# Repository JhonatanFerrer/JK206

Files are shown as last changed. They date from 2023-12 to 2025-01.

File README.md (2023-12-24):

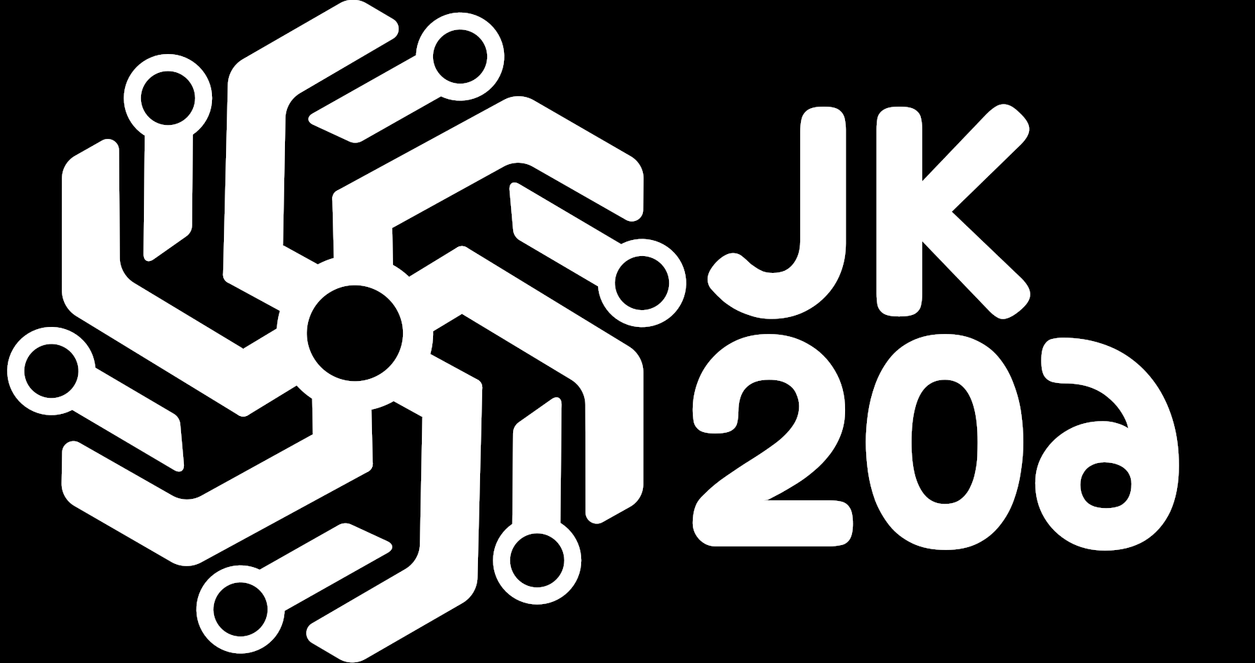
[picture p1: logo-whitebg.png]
Logo of the project


<h2 align="Left"> English </h2>

This project consists of a mechanical ortolinear keyboard design that is capable of being used for both a macropad and a 50% keyboard.

This is achieved through a modular design PCB that can be used by itself to mount a macropad with up to 20 keys (5 of them can be exchanged for encoders); while with three PCBs you can mount a keyboard with up to 60 keys (3 of them can be encoders)

The source code of the keyboard was written in CircuitPython using the <a href="http://kmkfw.io/">KMK firmware</a>, the microcontroller used is the Raspberry Pi Pico.

If you want to build your own JK206, go to the guide, where there will be the step-by-step to assemble and configure it

<strong>Note:</strong> If you just want to assemble your own JK206 and don't plan to modify anything of the PCB design, you don't need to touch the KiCAD files, directly use the Gerbers as the guide says

<h2 align="Left"> Español </h2>

Este proyecto consiste en un diseño de teclado mecánico ortolineal que es capaz de utilizarse tanto para un macropad como para un teclado 50%. 

Esto se consigue mediante una PCB de diseño modular que se puede usar por si misma para montar un macropad de hasta 20 teclas (5 de ellas se pueden cambiar por encoders); mientras que con tres PCBs se puede montar un teclado de hasta 60 teclas (3 de ellas pueden ser encoders)

El código fuente del teclado fue escrito en CircuitPython haciendo uso del <a href="http://kmkfw.io/">firmware KMK</a>, el microcontrolador utilizado es el Raspberry Pi Pico.

Si quieres armar tu propio JK206, entra en la guía, donde estará el paso a paso para ensamblarlo y configurarlo 

<strong>Nota:</strong> Si solo quieres montar tu propio JK206 y no piensan modificar nada del diseño de la PCB , no necesitas tocar los archivos de KiCAD, usa directamente los Gerbers como dice la guía

<h1 align="Left"> Photos / Fotos </h1>













These photos are from a prototype version of the project, the final version features some minor changes / Estas fotos son de una versión prototipo del proyecto, la versión final presenta algunos cambios menores

<h1 align="Left"> ToDo </h1>

1. Finish the Spanish guide and make the English guide. / Terminar la guía en español y hacer la guía en inglés
   
2. Make the keyboard compatible with <a href="https://peg.software/">Peg</a> / Hacer el teclado compatible con <a href="https://peg.software/">Peg</a>

3. Add the possibility to insert UNICODE characters (this causes keyboard crashes) / Agregar la posibilidad de insertar caracteres UNICODE (esto causa crasheos en el teclado)
  
4. Ensure that when the keyboard is connected, the computer does not display its storage, or at least displays it under the name JK206 / Hacer que al ser conectado el teclado, el computador no muestre su almacenamiento, o al menos lo muestre bajo el nombre Jk206

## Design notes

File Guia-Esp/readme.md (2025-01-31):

<h1 align="Left"> Guía ensamble </h1>

<h2 align="Left"> 1. Materiales Base</h2>

Para poder armar tu propio JK206, sea en su versión de macropad o de teclado 50%, necesitas los siguientes materiales:

| | Macropad | Teclado |
| --- | --- | --- |
| Switches mx | 15 - 20 (dependiendo el número de encoders) | 57 - 60 (dependiendo el número de encoders) |
| Sockets hotswap kailh | 15 - 20 (dependiendo el número de encoders) | 57 - 60 (dependiendo el número de encoders) |
| Encoders EC11 | 0 - 5 | 0 - 3 |
| Diodos 1n4148 | 20 | 60 |
| PCB JK206 | 1 | 3 |
| Raspberry Pi Pico | 1 | 1 |
| Pantalla OLED SSD1306 (0.91 o 0.96 pulgadas)  | 1 (opcional pero recomendada) | 1 (opcional pero recomendada) |
| Case | A preferencia | A preferencia |
| Keycaps | A preferencia | A preferencia |

Mas a continuación hablaremos de los tipos de case y que materiales en particular necesitan estos

Además de lo anterior, para poder realizar el montaje necesitarás de cautín/soldador y estaño, el flux de soldadura es opcional pero nunca viene mal para soldar

<h2 align="Left"> 2. Obtener la PCB </h2>

Para obtener las PCBs basta con tomar el gerber de la PCB (es un .zip) y mandarlo a hacer un una pagina de fabricación de PCBs. Solo hay que tener en cuenta que el número minimo de PCBs que se pueden mandar a hacer generalmente es de 5

<h2 align="Left"> 3. Preparar la PCB </h2>

Una vez tengas todos los materiales necesarios, toca empezar a soldar. Antes de empezar a soldar las piezas ten en cuenta lo siguiente según quieras montar un macropad o un teclado.

<h3 align="Left"> Para el macropad </h3>

Si estas montando el macropad, tienes que "habilitar" la opción de usar mas encoders en la PCB, para esto basta con unir los puntos de la PCB que se ven en la imagen, de forma que cada uno quede unido con quien tenga a sud derecha o izquierda

292385655-57addb74-b026-4cfa-8451-b28f55c42d1b

De forma que queden unidos de la siguiente manere



Esto se puede hacer tanto con cable UTP como con un jumper o uniendo directamente ambos puntos con estaño, basta con que haya continuidad entre ambos puntos

<h3 align="Left"> Para el teclado </h3>

Si estas montando el teclado, tienes que unir las 3 PCBs, para esto hay que unir filas y columnas; las columnas se unen en la parte superior de las PCBs de la siguiente forma:



Las filas se unen puenteando los puntos que se encuentran a los lados de la PCB junto al punto que le quede inmediatamente al lado de la otra PCB. Esto se hace en ambas intersecciones entre PCBs



No olvides que para evitar problemas posteriores con el montaje del teclado las 3 PCBs deben quedar completamente juntas y alineadas

<h2 align="Left"> 4. Soldar piezas </h2>

Ya con los preparativos listos, queda soldar los componentes en sus sitios correspondientes. Comienza colocando los diodos, estos van posicionados de forma que la parte que tiene una linea va hacia abajo, como se puede observar en la misma PCB



Lo siguiente sería soldar los sockets hotswap y los encoders, ten en cuenta que donde vayas a colocar enconders no hay que colocar sockets. Dependiendo de si estás armando un teclado o un macropad debes tener en cuenta las siguientes consideraciones:

<h3 align="Left"> Para el macropad </h3>

Los encoders se pueden colocar en el macropad de la siguiente forma



Las zonas verdes en el diagrama representan los puntos donde puenden colocarse los encoders. No es recomendable colocar dos encoders en posiciones que compartan el mismo número, pues por limitaciones del Raspberry Pi Pico y del diseño de la PCB estos serían reconocidos como un solo encoder; por lo que la formas recomendables de colocar los encoders serían las siguientes




<h3 align="Left"> Para el teclado </h3>

A pesar de tecnicamente poder poner encoders en la pcb de la izquierda en las posiciones 1, 2 y 3 mostradas en la sección anterior. Por cuestiones de usabilidad del teclado se recomienda solo poner un encoder en el extremo superior izquierdo.

Teniendo en cuenta lo anterior, empieza a soldar los sockets hotswap y los encoders que vayas a colocar. Puede que tengas problemas con los sockets, pero si eres generoso con el estaño no habrán mayores dificultades





Ahora solo faltaría soldar el Raspberry Pi Pico y la pantalla OLED. Es necesario que la Raspberry tenga pines soldados para poderla poner en la PCB, así que en caso de que tu Raspberry no los tenga de antemano tendrás que soldarle tu mismo unas regletas Antes de colocarla en la PCB.





En cuanto a la pantalla OLED, su posicionamiento varía dependiendo de cual pantalla vayas a usar. En caso de tener una pantalla rectangular de 0.91 pulgadas esta quedaría sobre la Raspberry, mientras que una pantalla cuadrada de 0.96 pulgadas quedaría a la derecha.




Nota: para el montaje del teclado, tanto la Raspberry como la pantalla van únicamente en la PCB de la izquierda. El diseño de la PCB no está pensado para que tomen ninguna otra posición.

<h2 align="Left"> 5. Montaje </h2>

Aquí el proceso cambia según el tipo de montaje que se quiera realizar:

<h3 align="Left"> Para el montaje sandwich-case </h3>

Para este montaje relativamente sencillo vas a necesitar de estos materiales:

| | Macropad | Teclado |
| --- | --- | --- |
| Separadores de latón M2 10mm | 4 | 4 |
| Tornillos M2 cabeza plana 6mm | 8 | 8 |
| Plates acrílicos (1.5mm de grosor)| [1 par](https://github.com/JhonatanFerrer/JK206/blob/main/Cases/Sandwich-Case/Macropad/Plates%20macropad.pdf)) | [1 par](https://github.com/JhonatanFerrer/JK206/blob/main/Cases/Sandwich-Case/Keyboard/Plates%20keyboard.pdf) |

Esta guía de montaje estará enfocada principalmente para el macropad, pero el montaje del JK206 en modo teclado es muy similar y la guía debería servir igualmente.

Para realizar el montaje del teclado o macropado lo primero será tomar el plate inferior y colocarle pies antideslizantes bajo preferencia del usuario.



Una vez hecho esto seguiría atornillar a éste los separadores





Nota: Los plates superior e inferior de la versión de teclado completo del JK206 tienen huecos para 12 separadores, aunque yo recomiendo usar solo 4 (2 al extremo derecho y 2 al extremo izquierdo),pero queda la opción de colocar mas separadores si se desea una sensación mas rígida al escribir

Ya teniendo nuestro plate inferior ahora vamos a sujetar nuestra PCB al plate superior con los switches, para esto basta con colocar un par de switches en el plate para luego colocarlos juntos en la PCB





Despues de esto quedaría colocar los switches faltantes



Ya teniendo unidos plate, pcb y switches podemos atornillar el plate superior a los separadores que habíamos colocado anteriormente en el plate inferior



Y con esto ya tenemos nuestro teclado o macropad listo, solo faltaría colocar keycaps a nuestro gusto y disfrutar.



<h4 align="Left"> Mods recomendados: </h4>
En general el tape mod funciona bien con el montaje, fuera de eso no hay mucho mas que se pueda hacer.

<h2 align="Left"> 5. Instalación del firmware </h2>

Ésta es la parte más fácil, para esto solo debes instalar [KMK](https://github.com/KMKfw/kmk_firmware/blob/main/docs/en/Getting_Started.md) en tu teclado o macropad siguiendo la guía de inicio rápido y sobre éste colocar los archivos de configuración, sean los del [macropad](https://github.com/JhonatanFerrer/JK206/tree/main/Source_Code/Macropad) o el [teclado completo](https://github.com/JhonatanFerrer/JK206/tree/main/Source_Code/Keyboard).

Y con ésto ya deberías tener completamente funcional tu JK206 :D

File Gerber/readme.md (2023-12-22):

<h2 align="Left"> English </h2>

Here are the Gerber files of the PCB, to send it to manufacture just upload the .zip file to your trusted PCB fabrication site (I recommend JLCPCB). When uploading the file to these pages you will get multiple options, just make sure that the PCB is manufactured in FR-4, that it has 2 layers and that it has a color of your liking; everything else you can leave untouched.

<h2 align="Left"> Español </h2>

Aquí se encuentran los archivos Gerber de la PCB, para mandarla a fabricar solo hace falta cargar el archivo .zip en tu página de fabricación de PCBs de confianza (yo recomiendo JLCPCB). Al subir el archivo a estas páginas van a salir multiples opciones, solo asegurate de que la PCB se fabrique en FR-4, que tenga 2 capas y que tenga un color de tu agrado; todo lo demás lo puedes dejar sin tocar.

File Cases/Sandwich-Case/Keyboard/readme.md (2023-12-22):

<h2 align="Left"> English </h2>

These are the PDF designs of the acrylic pieces needed for the Sandwich-Case type assembly of the keyboard. These pieces are designed to measure 2mm thick and can be made at any acrylic cutter shop by simply taking the PDF.

Remember that in order to assemble the macropad with this type of mounting you will also need a minimun of 8 M2 screws of 4 or 5mm along with 4 M2 spacers of 7mm, plus 6 rubber or silicone feet of your choice.

<h2 align="Left"> Español </h2>

Estos son los diseños en PDF de las piezas acrílicas necesarias para el montaje tipo Sandwich-Case del teclado. Estas piezas están pensadas para medir 2mm de grosor y se pueden mandar a hacer en cualquier local de venta y corte de acrilicos simplemente llevando el PDF

Recuerda que para poder armar el macropad con este tipo de montaje tambien vas a necesitar minimo 8 tornillos M2 de 4 o 5mm junto con 4 espaciadores M2 de 7mm, además de 6 pies de caucho o silicona de tu preferencia

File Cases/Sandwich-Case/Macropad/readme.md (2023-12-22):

<h2 align="Left"> English </h2>

These are the PDF designs of the acrylic pieces needed for the Sandwich-Case type assembly of the macropad. These pieces are designed to measure 2mm thick and can be made at any acrylic cutter shop by simply taking the PDF.

Remember that in order to assemble the macropad with this type of mounting you will also need 8 M2 screws of 4 or 5mm along with 4 M2 spacers of 7mm, plus 4 rubber or silicone feet of your choice.

<h2 align="Left"> Español </h2>

Estos son los diseños en PDF de las piezas acrílicas necesarias para el montaje tipo Sandwich-Case del macropad. Estas piezas están pensadas para medir 2mm de grosor y se pueden mandar a hacer en cualquier local de venta y corte de acrilicos simplemente llevando el PDF

Recuerda que para poder armar el macropad con este tipo de montaje tambien vas a necesitar 8 tornillos M2 de 4 o 5mm junto con 4 espaciadores M2 de 7mm, además de 4 pies de caucho o silicona de tu preferencia

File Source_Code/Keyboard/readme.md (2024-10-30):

<h2 align="Left"> English </h2>

This is the keyboard source code, to use it on your keyboard just put the files inside your keyboard following the tutorial. Don't forget that apart from needing to have CircuitPython with KMK, the keyboard needs the <a href="https://github.com/adafruit/Adafruit_CircuitPython_DisplayIO_SSD1306">DisplayIO_SSD1306</a> and <a href="https://github.com/adafruit/Adafruit_CircuitPython_Display_Text">CircuitPython_Display_Text</a> libraries.

This code assumes that the keyboard has a 0.96-inch SSD1306 OLED display, and the images were created with this in mind. In the guide there is a section for configuring the display

By default the way some symbols are written is set to Linux, but you can change it in the second line of main.py, changing SymbolsLinux to SymbolsWindows.



A Mac mode is not yet implemented

<h2 align="Left"> Español </h2>

Este es el código fuente del teclado, para usarlo en tu teclado solo pon los archivos dentro de tu teclado siguiendo el tutorial. No olvides que aparte de necesitar tener CircuitPython con KMK, el teclado necesita de las librerías <a href="https://github.com/adafruit/Adafruit_CircuitPython_DisplayIO_SSD1306">DisplayIO_SSD1306</a> y <a href="https://github.com/adafruit/Adafruit_CircuitPython_Display_Text">CircuitPython_Display_Text</a>

Este código asume que el teclado tiene una pantalla OLED SSD1306 de 0,96 pulgadas, además de que las imagenes fueron creadas tomando esto en cuenta. En la guía hay un apartado para configurar la pantalla.

De forma predeterminada la forma en que se escriben algunos símbolos está configurada para Linux, pero puede cambiarse en la segunda línea de main.py, cambiando SymbolsLinux a SymbolsWindows.



Aún no está implementado un modo para Mac

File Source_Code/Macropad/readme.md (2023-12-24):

<h2 align="Left"> English </h2>

This is the macropad source code, to use it on your keyboard just put the .py files inside your keyboard following the tutorial. Don't forget that apart from needing to have CircuitPython with KMK, the macropad needs the <a href="https://github.com/adafruit/Adafruit_CircuitPython_DisplayIO_SSD1306">DisplayIO_SSD1306</a> and <a href="https://github.com/adafruit/Adafruit_CircuitPython_Display_Text">CircuitPython_Display_Text</a> libraries.

This code assumes that the keyboard has a 0.91-inch SSD1306 OLED display, and the images were created with this in mind. In the guide there is a section for configuring the display.

By default the way some symbols are written is set to Linux, but you can change it in the second line of main.py, changing SymbolsLinux to SymbolsWindows.



A Mac mode is not yet implemented

<h2 align="Left"> Español </h2>

Este es el código fuente del macropad, para usarlo en tu teclado solo pon los archivos .py dentro de tu teclado siguiendo el tutorial. No olvides que aparte de necesitar tener CircuitPython con KMK, el macropad necesita de las librerías <a href="https://github.com/adafruit/Adafruit_CircuitPython_DisplayIO_SSD1306">DisplayIO_SSD1306</a> y <a href="https://github.com/adafruit/Adafruit_CircuitPython_Display_Text">CircuitPython_Display_Text</a>

Este código asume que el teclado tiene una pantalla OLED SSD1306 de 0,96 pulgadas, además de que las imagenes fueron creadas tomando esto en cuenta. En la guía hay un apartado para configurar la pantalla.

De forma predeterminada la forma en que se escriben algunos símbolos está configurada para Linux, pero puede cambiarse en la segunda línea de main.py, cambiando SymbolsLinux a SymbolsWindows.



Aún no está implementado un modo para Mac

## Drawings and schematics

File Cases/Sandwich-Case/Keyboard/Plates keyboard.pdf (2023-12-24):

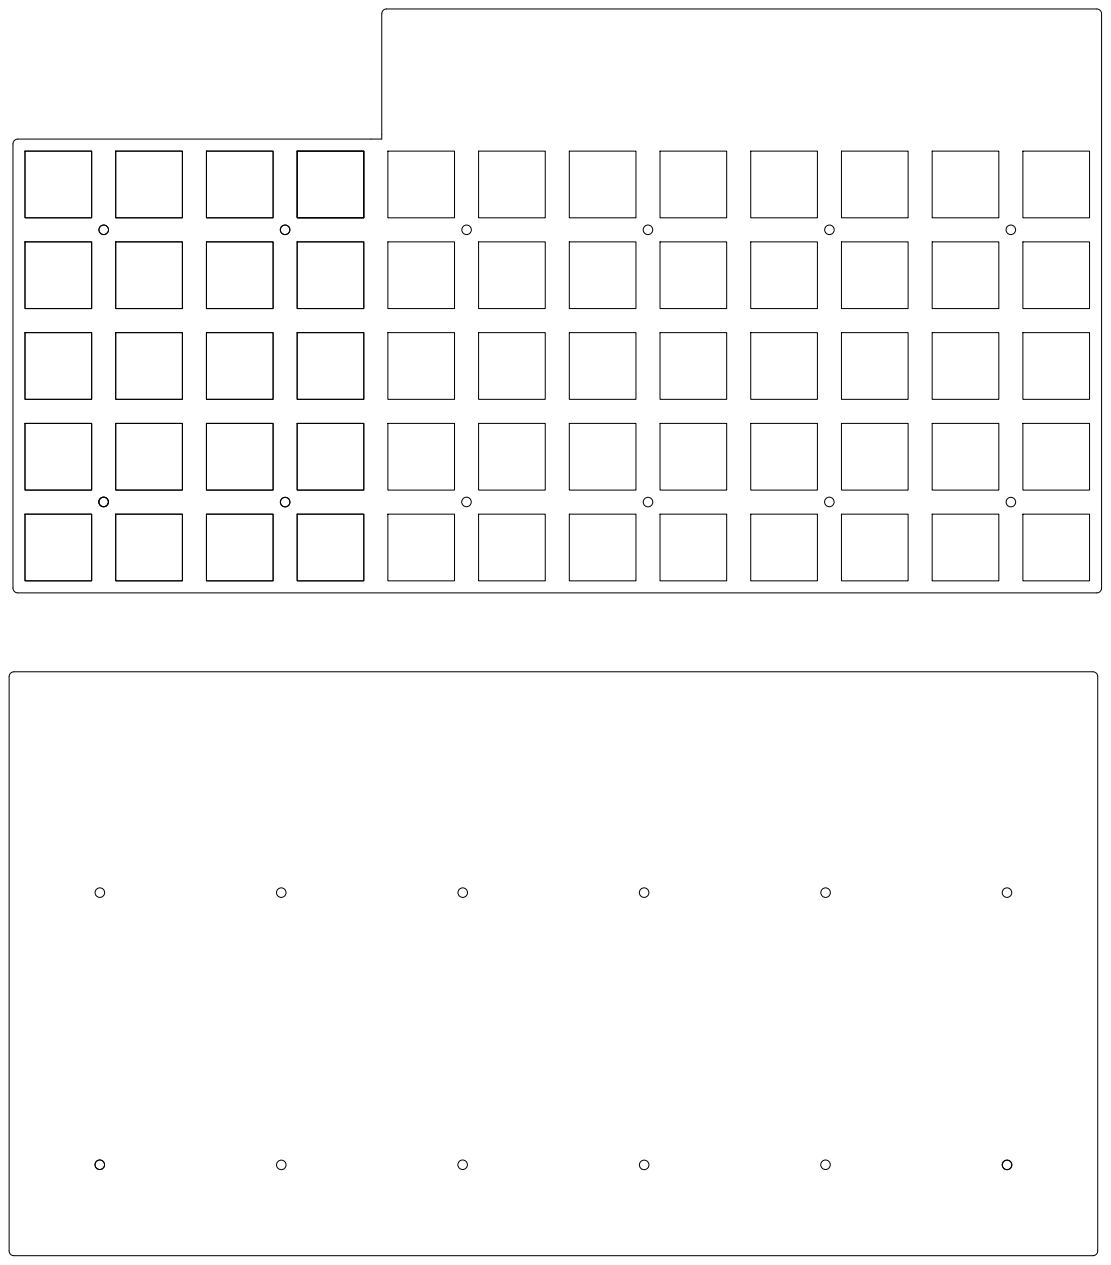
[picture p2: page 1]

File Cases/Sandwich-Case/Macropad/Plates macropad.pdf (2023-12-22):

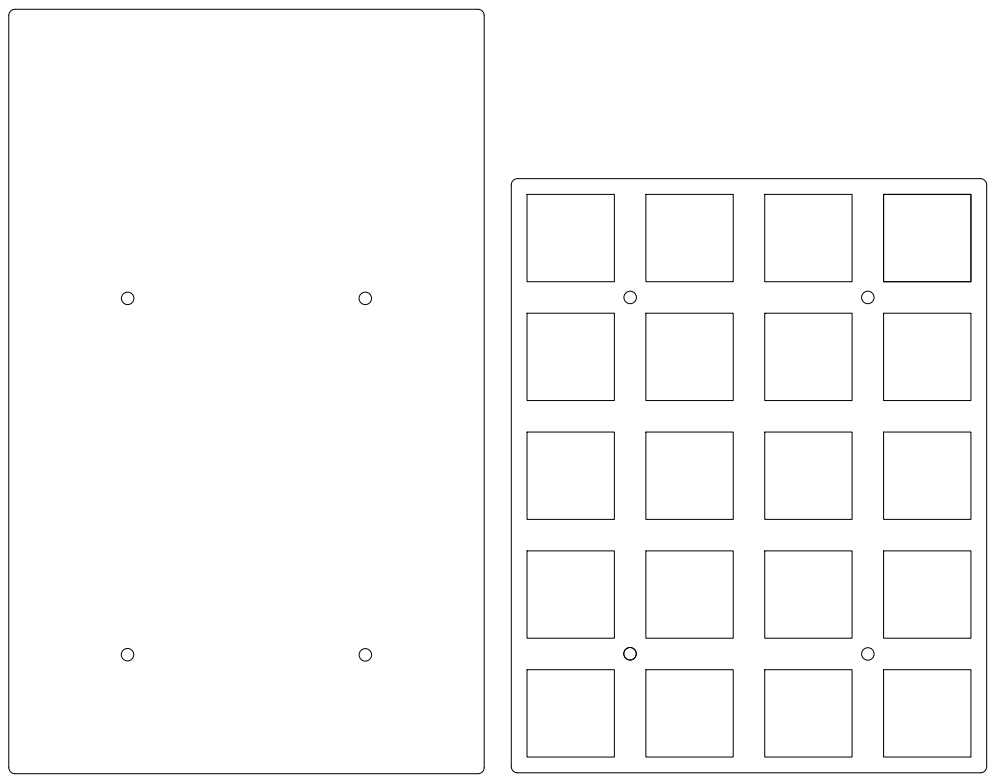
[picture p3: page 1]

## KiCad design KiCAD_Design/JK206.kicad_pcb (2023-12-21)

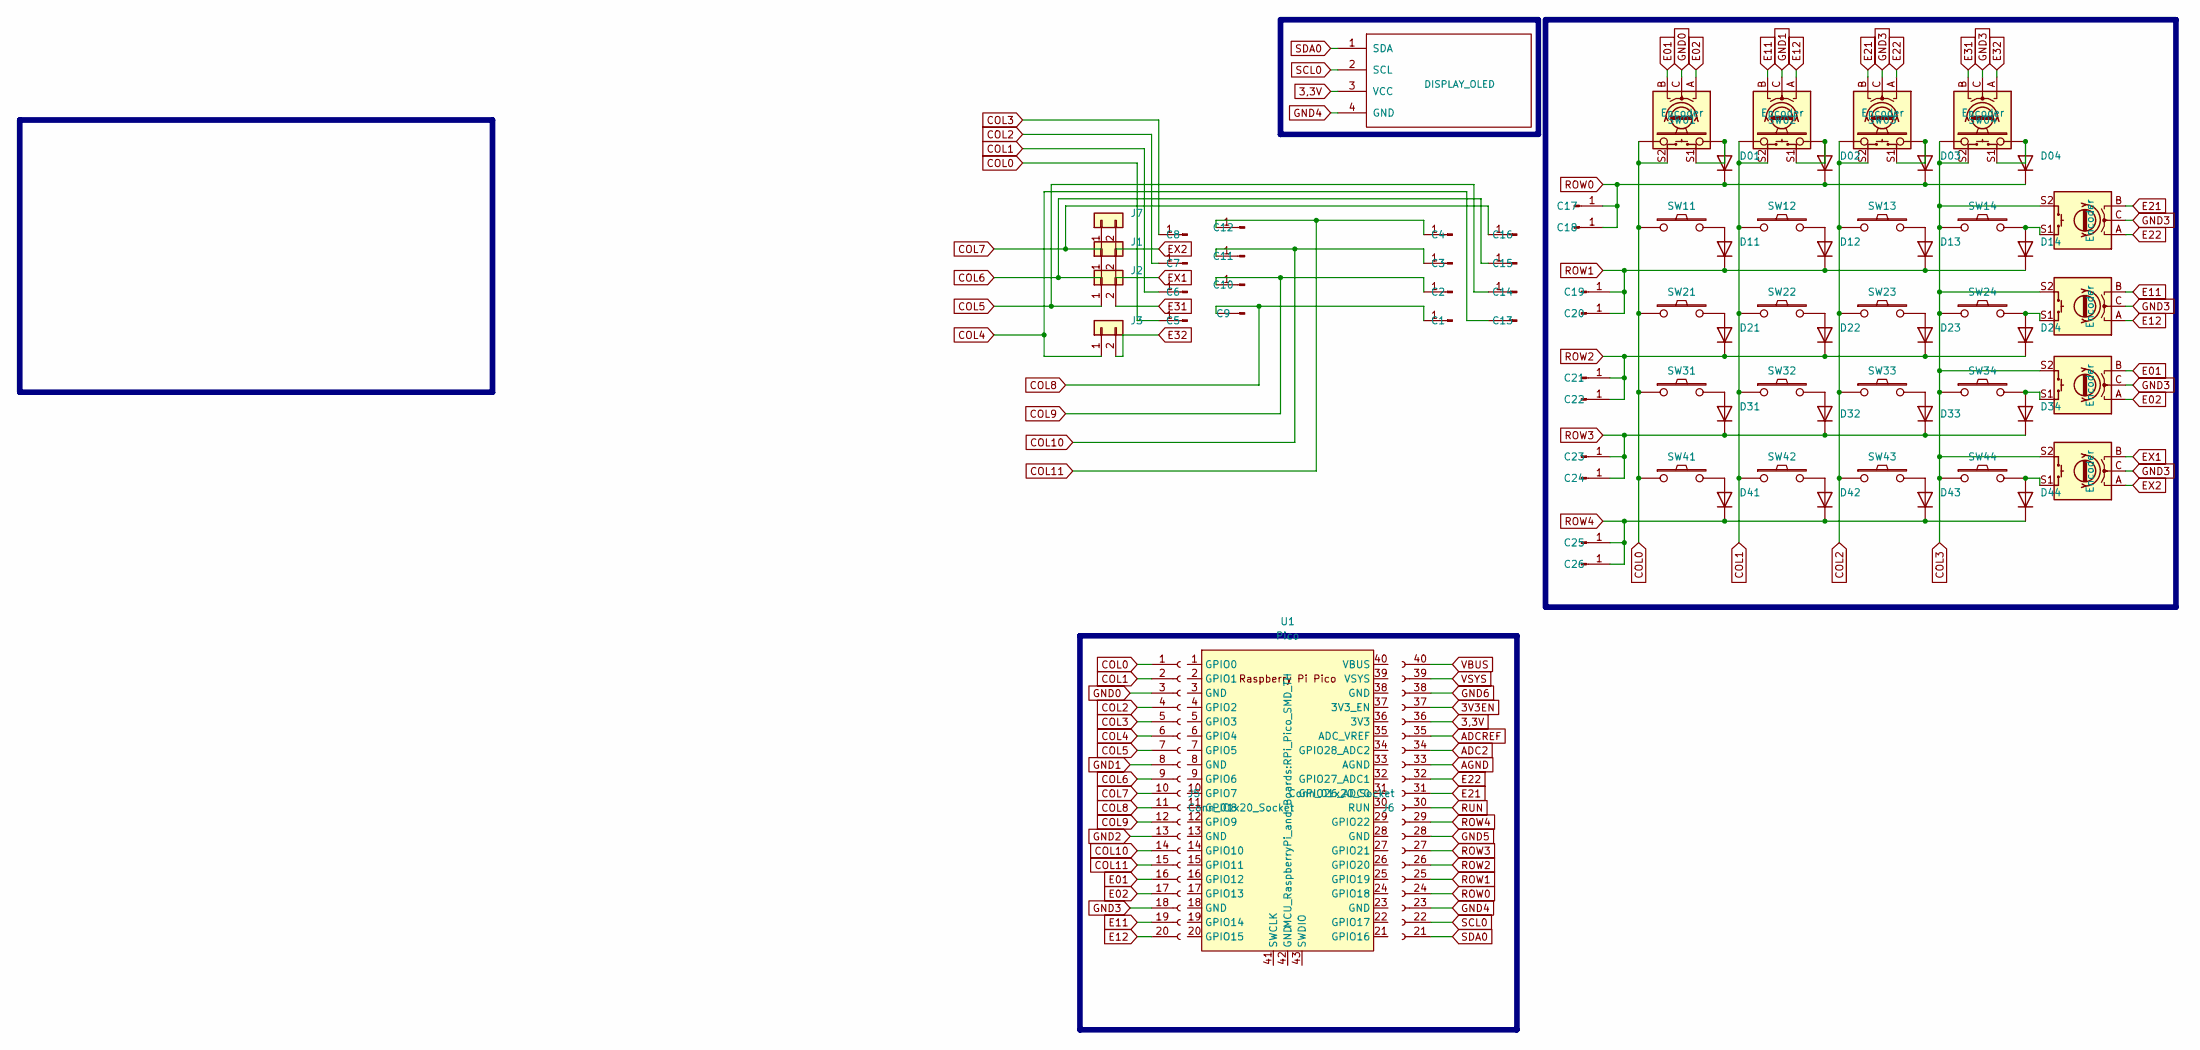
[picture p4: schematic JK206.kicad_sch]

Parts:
C1, C2, C3, C4, C5, C6, C7, C8, C9, C10, C11, C12, C13, C14, C15, C16: Conn_01x01_Pin; Pin_D1.0mm_L10.0mm
C17, C18, C19, C20, C21, C22, C23, C24, C25, C26: Conn_01x01_Pin; SolderWire-0.1sqmm_1x01_D0.4mm_OD1mm
D01, D02, D03, D04, D11, D12, D13, D14, D21, D22, D23, D24, D31, D32, D33, D34, D41, D42, D43, D44: 1N4148; D_DO-35_SOD27_P7.62mm_Horizontal
J1, J2, J3, J7: Connector_Generic_Conn_01x02; PinSocket_1x02_P2.54mm_Vertical
J5, J6: Conn_01x20_Socket; PinSocket_1x20_P2.54mm_Vertical
OL1: DISPLAY_OLED; 128x64OLED
SW01, SW02, SW03, SW04, SW11, SW12, SW13, SW14, SW21, SW22, SW23, SW24, SW31, SW32, SW33, SW34, SW41, SW42, SW43, SW44: SW_PUSH; CherryMX_Hotswap
SW5, SW18, SW19, SW20, SW25, SW26, SW27, SW28: Encoder; RotaryEncoder_Alps_EC11E-Switch_Vertical_H20mm
U1: Pico; RPi_Pico_SMD_TH

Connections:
3,3V: J6.36 (Pin_16), OL1.3 (VCC); also elsewhere on the board
3V3EN: J6.37 (Pin_17)
ADC2: J6.34 (Pin_14)
ADCREF: J6.35 (Pin_15)
AGND: J6.33 (Pin_13)
COL0: C5.1, J5.1, SW01.1, SW5.S2, SW11.1, SW21.1, SW31.1, SW41.1
COL1: C6.1, J5.2, SW02.1, SW12.1, SW18.S2, SW22.1, SW32.1, SW42.1
COL2: C7.1, J5.4, SW03.1, SW13.1, SW19.S2, SW23.1, SW33.1, SW43.1
COL3: C8.1, J5.5, SW04.1, SW14.1, SW20.S2, SW24.1, SW25.S2, SW26.S2, SW27.S2, SW28.S2, SW34.1, SW44.1
COL4: C13.1, J3.1, J5.6
COL5: C14.1, J2.1, J5.7
COL6: C15.1, J1.1, J5.9
COL7: C16.1, J5.10, J7.1
COL8: C1.1, C9.1, J5.11
COL9: C2.1, C10.1, J5.12
COL10: C3.1, C11.1, J5.14
COL11: C4.1, C12.1, J5.15
E01: J5.16, SW5.B, SW27.B
E02: J5.17, SW5.A, SW27.A
E11: J5.19, SW18.B, SW26.B
E12: J5.20, SW18.A, SW26.A
E21: J6.31 (Pin_11), SW19.B, SW25.B
E22: J6.32 (Pin_12), SW19.A, SW25.A
E31: J2.2, SW20.B
E32: J3.2, SW20.A
EX1: J1.2, SW28.B
EX2: J7.2, SW28.A
GND0: J5.3, SW5.C
GND1: J5.8, SW18.C
GND2: J5.13
GND3: J5.18, SW19.C, SW20.C, SW25.C, SW26.C, SW27.C, SW28.C
GND4: J6.23 (Pin_3), OL1.4 (GND); also elsewhere on the board
GND5: J6.28 (Pin_8)
GND6: J6.38 (Pin_18)
unnamed: D01.2 (A), SW01.2, SW5.S1
unnamed: D02.2 (A), SW02.2, SW18.S1
unnamed: D03.2 (A), SW03.2, SW19.S1
unnamed: D04.2 (A), SW04.2, SW20.S1
unnamed: D11.2 (A), SW11.2
unnamed: D12.2 (A), SW12.2
unnamed: D13.2 (A), SW13.2
unnamed: D14.2 (A), SW14.2, SW25.S1
unnamed: D21.2 (A), SW21.2
unnamed: D22.2 (A), SW22.2
unnamed: D23.2 (A), SW23.2
unnamed: D24.2 (A), SW24.2, SW26.S1
unnamed: D31.2 (A), SW31.2
unnamed: D32.2 (A), SW32.2
unnamed: D33.2 (A), SW33.2
unnamed: D34.2 (A), SW27.S1, SW34.2
unnamed: D41.2 (A), SW41.2
unnamed: D42.2 (A), SW42.2
unnamed: D43.2 (A), SW43.2
unnamed: D44.2 (A), SW28.S1, SW44.2
ROW0: C17.1, C18.1, D01.1 (K), D02.1 (K), D03.1 (K), D04.1 (K), J6.24 (Pin_4)
ROW1: C19.1, C20.1, D11.1 (K), D12.1 (K), D13.1 (K), D14.1 (K), J6.25 (Pin_5)
ROW2: C21.1, C22.1, D21.1 (K), D22.1 (K), D23.1 (K), D24.1 (K), J6.26 (Pin_6)
ROW3: C23.1, C24.1, D31.1 (K), D32.1 (K), D33.1 (K), D34.1 (K), J6.27 (Pin_7)
ROW4: C25.1, C26.1, D41.1 (K), D42.1 (K), D43.1 (K), D44.1 (K), J6.29 (Pin_9)
RUN: J6.30 (Pin_10)
SCL0: J6.22 (Pin_2), OL1.2 (SCL); also elsewhere on the board
SDA0: J6.21 (Pin_1), OL1.1 (SDA); also elsewhere on the board
VBUS: J6.40 (Pin_20)
VSYS: J6.39 (Pin_19)

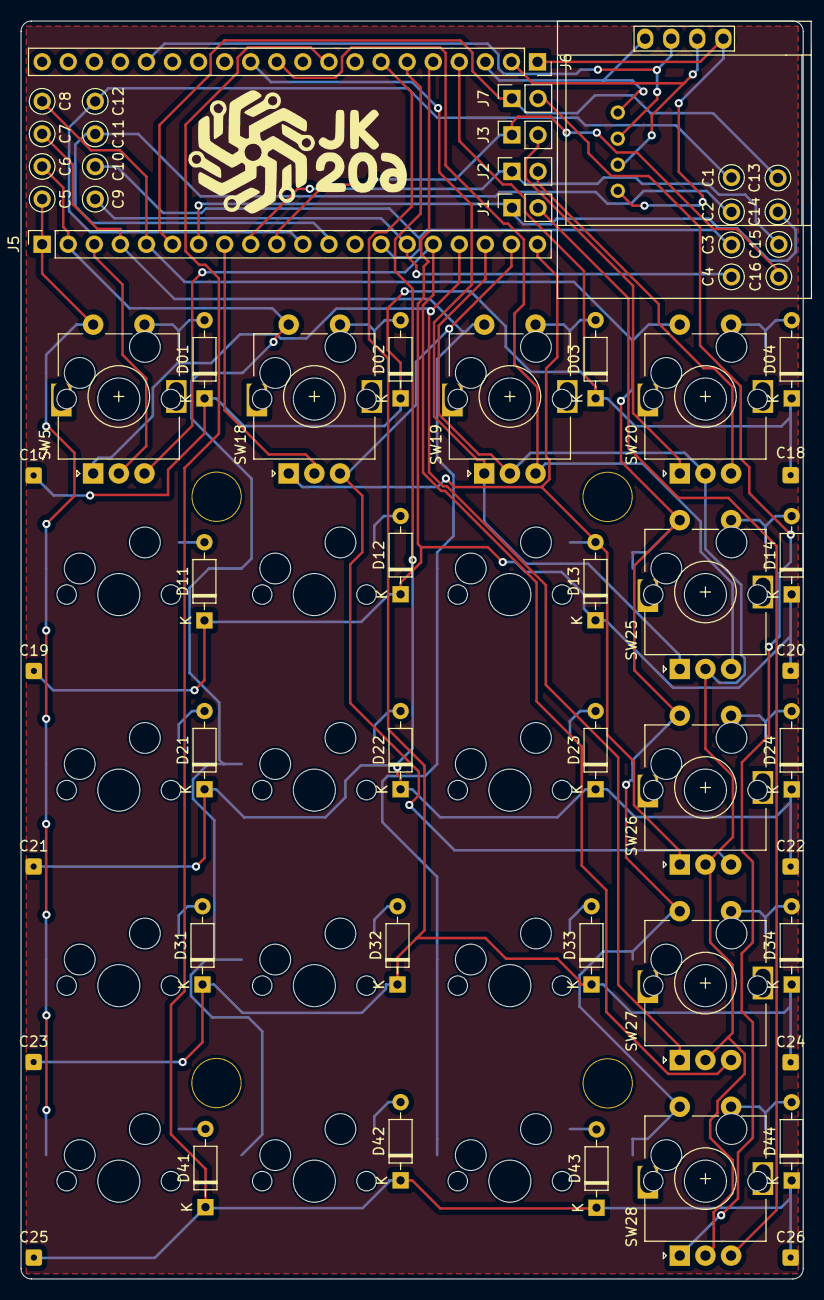
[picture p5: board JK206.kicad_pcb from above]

Board: 2 copper layers, 76.2 x 122.6 mm, 82 parts (0 on the bottom side), 54 nets.

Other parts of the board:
OL1#2: DISPLAY_OLED; 128x64OLED

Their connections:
3,3V: OL1#2.2 (SCL); also elsewhere on the board
GND4: OL1#2.1 (SDA); also elsewhere on the board
SCL0: OL1#2.3 (VCC); also elsewhere on the board
SDA0: OL1#2.4 (GND); also elsewhere on the board

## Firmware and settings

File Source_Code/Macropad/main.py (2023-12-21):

from kb import KMKKeyboard 
from symbols import SymbolsLinux as Symbols
from combinations import Combinations
from kmk.keys import KC
from kmk.modules.layers import Layers
from kmk.modules.encoder import EncoderHandler
from kmk.extensions.media_keys import MediaKeys
from kmk.extensions.peg_oled_Display import Oled,OledDisplayMode,OledReactionType,OledData

Keyboard = KMKKeyboard()
Keyboard.modules.append(Layers())
Keyboard.extensions.append(MediaKeys()) 


OledConfiguration = Oled(
      OledData(image={0:OledReactionType.LAYER,1:["logo.bmp","logo.bmp","KBNums.bmp","FNKeys.bmp","KeyComb.bmp"]}),
      oWidth=128,oHeight=32,toDisplay=OledDisplayMode.IMG,flip=True
    )
Keyboard.extensions.append(OledConfiguration)

encoder_handler = EncoderHandler() 
encoder_handler.pins = Keyboard.encoderPins

encoder_handler.map = (
    ((KC.VOLD, KC.VOLU,),(KC.UP, KC.DOWN,),(KC.LEFT, KC.RIGHT,),(KC.TO(4), KC.TO(2),),),  # Layer 0
    ((KC.VOLD, KC.VOLU,),(KC.UP, KC.DOWN,),(KC.LEFT, KC.RIGHT,),(KC.NO, KC.NO,),),        # Layer 1
    ((KC.VOLD, KC.VOLU,),(KC.UP, KC.DOWN,),(KC.LEFT, KC.RIGHT,),(KC.TO(0), KC.TO(3)),),   # Layer 2
    ((KC.VOLD, KC.VOLU,),(KC.UP, KC.DOWN,),(KC.LEFT, KC.RIGHT,),(KC.TO(2), KC.TO(4)),),   # Layer 3
    ((KC.VOLD, KC.VOLU,),(KC.UP, KC.DOWN,),(KC.LEFT, KC.RIGHT,),(KC.TO(3), KC.TO(0),),),  # Layer 4
)
Keyboard.modules.append(encoder_handler)

Keyboard.keymap = [
    # Layer 0 NUMPAD
   [
     KC.MEDIA_PLAY_PAUSE,  KC.HOME,           KC.END,           KC.ESCAPE,
     KC.P2,                KC.P8,             KC.P9,            KC.KP_SLASH,
     KC.P4,                KC.P5,             KC.P6,            KC.KP_ASTERISK,
     KC.P1,                KC.P2,             KC.P3,            KC.KP_MINUS,
     KC.P0,                KC.PDOT,           KC.KP_PLUS,       KC.MO(1),
   ], 
   # Layer 1 NUMPAD Extras
   [  
     KC.MEDIA_PLAY_PAUSE,  KC.HOME,           KC.END,           KC.ESCAPE,
     KC.P7,                KC.P8,             KC.P9,            KC.KP_SLASH,
     KC.P4,                KC.UP,             KC.P6,            KC.KP_ASTERISK,
     KC.LEFT,              KC.DOWN,           KC.RIGHT,         KC.BSPACE,
     KC.P0,                KC.PENT,           KC.KP_EQUAL,      KC.NO,
   ],
   # Layer 2 Main keyboard numbers (if you need them in specific)
   [  
     KC.MEDIA_PLAY_PAUSE,  KC.HOME,           KC.END,           KC.ESCAPE,
     KC.N7,                KC.N8,             KC.N9,            KC.KP_SLASH,
     KC.N4,                KC.N5,             KC.N6,            KC.KP_ASTERISK,
     KC.N1,                KC.N2,             KC.N3,            KC.KP_MINUS,
     KC.N0,                KC.PDOT,           KC.KP_PLUS,       KC.MO(1),
   ],
   # Layer 3 Function keys
   [  
     KC.MEDIA_PLAY_PAUSE,  KC.HOME,           KC.END,           KC.ESCAPE,
     KC.F9,                KC.F10,            KC.F11,           KC.F12,
     KC.F5,                KC.F6,             KC.F7,            KC.F8,
     KC.F1,                KC.F2,             KC.F3,            KC.F4,
     KC.PSCREEN,           KC.DELETE,         KC.INSERT,        KC.APPLICATION,
   ],
   # Layer 4 Common keys combination
   [  
     KC.MEDIA_PLAY_PAUSE,  KC.HOME,           KC.END,           KC.ESCAPE,
     KC.NO,                KC.NO,             KC.NO,            KC.NO,
     KC.NO,                KC.NO,             KC.NO,            KC.NO,
     Combinations.Save,    Combinations.Undo, Combinations.Redo,Combinations.CtrlAltDel,
     Combinations.Copy,    Combinations.Paste,Combinations.Cut, Combinations.AltTab,
   ]
]




if __name__ == '__main__':
    Keyboard.go()

 #

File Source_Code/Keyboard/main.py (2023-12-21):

from kb import KMKKeyboard
from symbols import SymbolsLinux as Symbols
from combinations import Combinations
from kmk.keys import KC
from kmk.modules.layers import Layers
from kmk.modules.encoder import EncoderHandler
from kmk.extensions.media_keys import MediaKeys
from kmk.extensions.peg_oled_Display import Oled,OledDisplayMode,OledReactionType,OledData

Keyboard = KMKKeyboard()
Keyboard.modules.append(Layers())
Keyboard.extensions.append(MediaKeys())



OledConfiguration = Oled(
      OledData(image={0:OledReactionType.LAYER,1:["Logo.bmp","Fn.bmp","Extras.bmp", "Game.bmp"]}),
      oWidth=128,oHeight=64,toDisplay=OledDisplayMode.IMG,
    )
Keyboard.extensions.append(OledConfiguration)

encoder_handler = EncoderHandler()
encoder_handler.pins = Keyboard.encoderPins

encoder_handler.map = (
    ((KC.VOLD, KC.VOLU,),),  # Layer 0
    ((KC.VOLD, KC.VOLU,),),  # Layer 1
    ((KC.VOLD, KC.VOLU,),),  # Layer 2
    ((KC.VOLD, KC.VOLU,),),  # Layer 3¿¿¿¿¿¿¿
)

Keyboard.modules.append(encoder_handler)

Keyboard.keymap = [
    # Layer 0 BASE
   [
     KC.MEDIA_PLAY_PAUSE, KC.N1,        KC.N2,      KC.N3,       KC.N4,        KC.N5,      KC.N6,         KC.N7,        KC.N8,      KC.N9,      KC.N0,                KC.BSPC,
     KC.ESC,              KC.Q,         KC.W,       KC.E,        KC.R,         KC.T,       KC.Y,          KC.U,         KC.I,       KC.O,       KC.P,                 KC.QUOTE,
     KC.TAB,              KC.A,         KC.S,       KC.D,        KC.F,         KC.G,       KC.H,          KC.J,         KC.K,       KC.L,       KC.SCOLON,            KC.ENTER,
     KC.LSHIFT,           KC.Z,         KC.X,       KC.C,        KC.V,         KC.B,       KC.N,          KC.M,         KC.COMMA,   KC.DOT,     KC.SLASH,             KC.RSHIFT,
     KC.LCTRL ,           KC.LGUI,      KC.PGUP,   KC.LALT,      KC.MO(2),     KC.SPACE,   KC.SPACE,      KC.MO(2),    KC.RALT,    KC.PGDOWN,   KC.RCTRL,             KC.MO(1),
   ],
   # Layer 1 FN
   [ 
     KC.F1,               KC.F2,        KC.F3,      KC.F4,       KC.F5,        KC.F6,      KC.F7,         KC.F8,        KC.F9,      KC.F10,      KC.F11,              KC.F12,
     KC.ESC,              KC.Q,         KC.W,       KC.E,        KC.R,         KC.T,       KC.Y,          KC.U,         KC.I,       KC.O,       KC.P,                 KC.QUOTE,
     KC.TAB,              KC.A,         KC.S,       KC.D,        KC.F,         KC.G,       KC.H,          KC.J,         KC.K,       KC.L,       KC.SCOLON,            KC.ENTER,
     KC.LSHIFT,           KC.Z,         KC.X,       KC.C,        KC.V,         KC.B,       Symbols.enie,  KC.M,         KC.COMMA,   KC.UP ,     KC.SLASH,             KC.RSHIFT,
     KC.LCTRL ,           KC.LGUI,      KC.PGUP,    KC.LALT,     KC.NO,        KC.SPACE,   KC.SPACE,      KC.NO,        KC.LEFT,    KC.DOWN,    KC.RIGHT,             KC.NO,
   ],
     # Layer 2 extra Simbols / Delete, printscreen and caps lock
   [
     KC.TO(3),            KC.N1,        KC.N2,      KC.N3,       KC.N4,        KC.N5,      KC.N6,         KC.N7,        KC.N8,      KC.N9,      KC.N0,                KC.DELETE,
     Symbols.grado,       KC.PLUS,      KC.MINUS,   KC.EQUAL,    KC.UNDERSCORE,KC.T,       KC.Y,          KC.U,         KC.I,       KC.O,       KC.P,                 KC.PSCREEN,
     KC.TAB,              KC.LCBR,      KC.RCBR,    KC.PIPE,     KC.BACKSLASH, KC.G,       KC.H,          KC.J,         KC.K,       KC.L,       KC.SCOLON,            KC.ENTER,
     KC.CAPS,             KC.LBRACKET,  KC.RBRACKET,KC.C,        KC.V,         KC.B,       KC.N,          KC.M,         KC.COMMA,   KC.DOT,     Symbols.abrirpregunta,KC.RSHIFT,
     KC.LCTRL ,           KC.LGUI,      KC.PGUP,    KC.LALT,     KC.NO,        KC.SPACE,   KC.SPACE,      KC.NO,        KC.RALT,    KC.PGDOWN,  KC.RCTRL,             KC.NO,
   ],
    # Layer 3 Game: permanents arrows and extended space
   [
     KC.TO(0),            KC.N1,        KC.N2,      KC.N3,       KC.N4,        KC.N5,      KC.N6,         KC.N7,        KC.N8,      KC.N9,      KC.N0,                KC.BSPC,
     KC.ESC,              KC.Q,         KC.W,       KC.E,        KC.R,         KC.T,       KC.Y,          KC.U,         KC.I,       KC.O,       KC.P,                 KC.QUOTE,
     KC.TAB,              KC.A,         KC.S,       KC.D,        KC.F,         KC.G,       KC.H,          KC.J,         KC.K,       KC.L,       KC.SCOLON,            KC.ENTER,
     KC.LSHIFT,           KC.Z,         KC.X,       KC.C,        KC.V,         KC.B,       KC.N,          KC.M,         KC.COMMA,   KC.UP,      KC.SLASH,             KC.RSHIFT,
     KC.LCTRL ,           KC.LGUI,      KC.PGUP,    KC.LALT,     KC.SPACE,     KC.SPACE,   KC.SPACE,      KC.SPACE,     KC.LEFT,    KC.DOWN,    KC.RIGHT,             KC.MO(1),
   ]
]



if __name__ == '__main__':
    Keyboard.go()

 #

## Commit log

2025-01-14 imágenes agregadas a la guía de armado en español
2025-01-14 ajustes menores en la guía en español
2025-01-14 arreglando numeración en la guía de ensamble
2025-01-23 Guía de ensamble terminada (solo con montaje tipo sandwich)
2025-01-23 cambio en el título de la guía
